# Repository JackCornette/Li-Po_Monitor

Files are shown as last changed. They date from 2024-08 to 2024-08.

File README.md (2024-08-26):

# Li-Po_Monitor
Custom Voltage and Current LiPo monitor PCB with SPI-CAN Circuit, LCD Display and piezo buzzer. Current is measured via through-hole Hall-Effect sensor with an analog output while voltage is measured in each Li-Po cell using an extended ADC IC. This was designed to monitor the Li-Po Batteries used on the Sooner Rover Team and facilitate simple integration into the CAN-Bus. 

## Parts List
- Seeed Studio XIAO mcu
- MCP3208 ADC Extension IC (SPI)
- SSD1306 LCD Display (128x64, SPI)
- WCS1700 35A Current Sensor
- MCP2515 CAN Controller (SPI)
- MAX3051 CAN Transceiver
- 8 MHz Crystal Oscillator
- LM397 Comparator
- BZV5583v3 Zener Diode
- BS108 MOSFET
- 0805 SMD Resistors
- 0805 SMD Capacitors
- 0805 LEDs
- Piezo Buzzer
- 2.54 mm Pin Headers/ Connectors
- 1x2 Screw Terminal

## Schematic
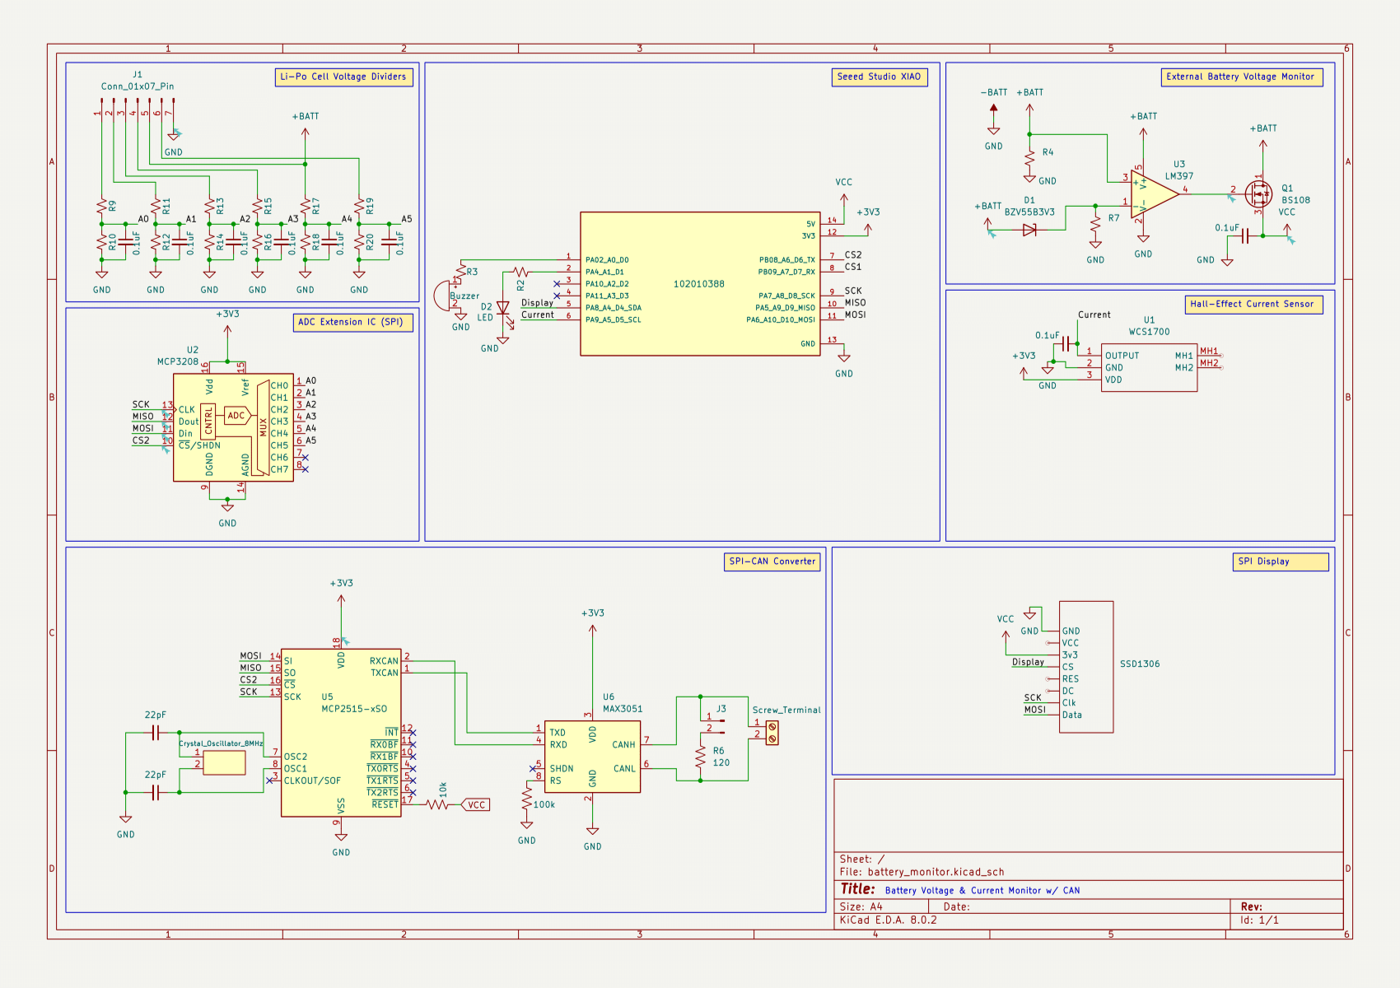
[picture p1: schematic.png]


## PCB Design
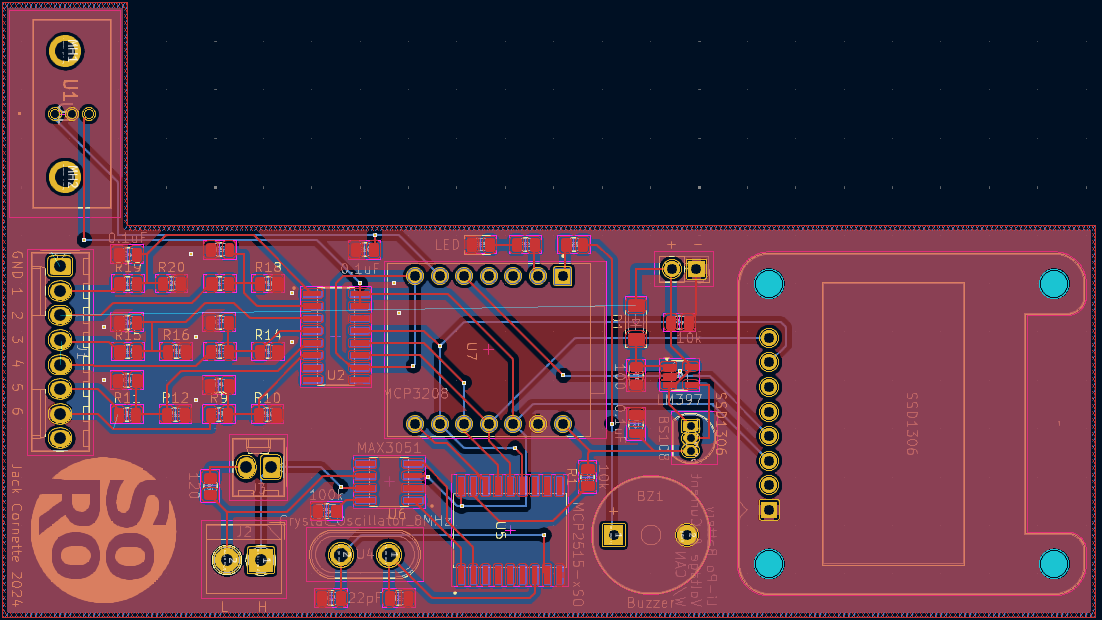
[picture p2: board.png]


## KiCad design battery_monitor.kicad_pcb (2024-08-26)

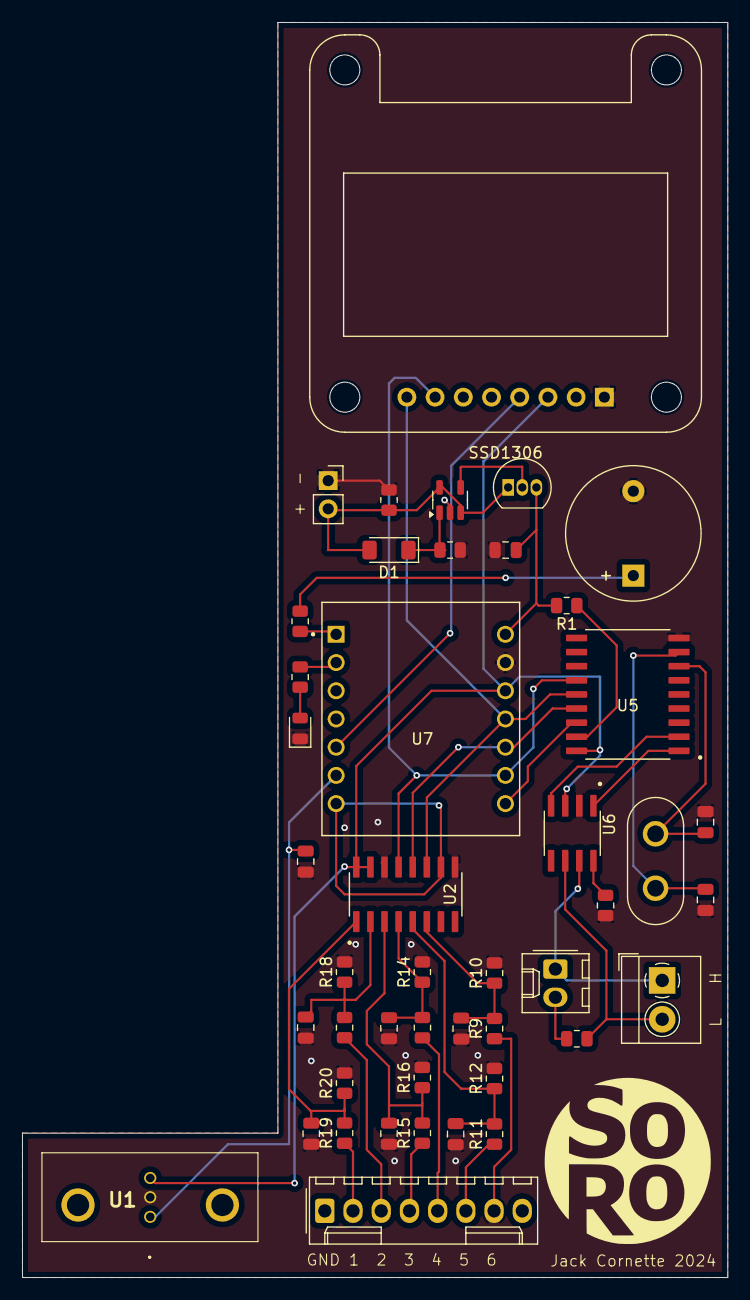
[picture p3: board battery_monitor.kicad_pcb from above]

Board: 2 copper layers, 63.5 x 113.0 mm, 44 parts (0 on the bottom side), 35 nets.

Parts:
BZ1: Buzzer; Buzzer_12x9.5RM7.6
C1, C2: 22pF; C_0805_2012Metric
C3, C4, C5, C6, C7, C8, C9, C10: 0.1uF; C_0805_2012Metric
D1: BZV55B3V3; D_MiniMELF
D2: LED; LED_0805_2012Metric
J1: Conn_01x07_Pin; Molex_KK-254_AE-6410-08A_1x08_P2.54mm_Vertical
J2: Screw_Terminal; TerminalBlock_4Ucon_1x02_P3.50mm_Horizontal
J3: Conn_01x02_Pin; Molex_KK-254_AE-6410-02A_1x02_P2.54mm_Vertical
Q1: BS108; TO-92_Inline
R1, R4: 10k; R_0805_2012Metric
R2, R3, R9, R10, R11, R12, R13, R14, R15, R16, R17, R18, R19, R20: R_Small_US; R_0805_2012Metric
R5: 100k; R_0805_2012Metric
R6: 120; R_0805_2012Metric
R7: 100; R_0805_2012Metric
SSD1306: Adafruit_SSD1306
U1: WCS1700
U2: MCP3208; SOIC127P600X175-16N
U3: LM397; SOT-23-5
U4: Crystal_Oscillator_8MHz; Crystal_HC50_Vertical
U5: MCP2515-xSO; SOIC127P1030X265-18N
U6: MAX3051; SOIC127P600X175-8N
U7: 102010388; MODULE_102010388

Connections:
+3V3: SSD1306.3, U1.3 (VDD), U2.15 (Vref), U2.16 (Vdd), U5.18 (VDD), U6.3 (VDD), U7.12 (3V3)
+BATT: D1.2 (A), J1.3, Q1.1 (D), R4.1, U3.3 (+), U3.5 (V+)
-BATT: BZ1.2 (-), C1.2, C2.2, C3.1, C4.2, C5.2, C6.2, C7.2, C8.2, C9.2, C10.1, D2.1 (K), J1.1, R4.2, R5.2, R7.2, R10.2, R12.2, R14.2, R16.2, R18.2, R20.2, SSD1306.1, U1.2 (GND), U2.9 (DGND), U2.14 (AGND), U3.2 (V-), U5.9 (VSS), U6.2 (GND), U7.13 (GND)
/A0: C4.1, R19.2, R20.1, U2.1 (CH0)
/A1: C5.1, R17.2, R18.1, U2.2 (CH1)
/A2: C6.1, R15.2, R16.1, U2.3 (CH2)
/A3: C7.1, R13.2, R14.1, U2.4 (CH3)
/A4: C8.1, R11.2, R12.1, U2.5 (CH4)
/A5: C9.1, R9.2, R10.1, U2.6 (CH5)
/CS1: U5.16 (~CS), U7.8 (PB09_A7_D7_RX)
/CS2: U2.10 (~CS/SHDN), U7.7 (PB08_A6_D6_TX)
/Current: C10.2, U1.1 (OUTPUT), U7.6 (PA9_A5_D5_SCL)
/Display: SSD1306.4, U7.5 (PA8_A4_D4_SDA)
/MISO: U2.12 (Dout), U5.15 (SO), U7.10 (PA5_A9_D9_MISO)
/MOSI: SSD1306.8, U2.11 (Din), U5.14 (SI), U7.11 (PA6_A10_D10_MOSI)
/SCK: SSD1306.7, U2.13 (CLK), U5.13 (SCK), U7.9 (PA7_A8_D8_SCK)
unnamed: BZ1.1 (+), R3.1
unnamed: D1.1 (K), R7.1, U3.1 (-)
unnamed: D2.2 (A), R2.2
unnamed: J1.2, R19.1
unnamed: J1.4, R13.1, R15.1
unnamed: J1.6, R11.1
unnamed: J2.1, J3.1, U6.7 (CANH)
unnamed: J2.2, R6.2, U6.6 (CANL)
unnamed: J3.2, R6.1
unnamed: Q1.2 (G), U3.4
unnamed: C2.1, U4.2, U5.8 (OSC1)
unnamed: C1.1, U4.1, U5.7 (OSC2)
unnamed: U5.2 (RXCAN), U6.4 (RXD)
unnamed: U5.1 (TXCAN), U6.1 (TXD)
unnamed: R1.1, U5.17 (~RESET)
unnamed: R5.1, U6.8 (RS)
unnamed: R3.2, U7.1 (PA02_A0_D0)
unnamed: R2.1, U7.2 (PA4_A1_D1)
VCC: C3.2, Q1.3 (S), R1.2, U7.14 (5V)
